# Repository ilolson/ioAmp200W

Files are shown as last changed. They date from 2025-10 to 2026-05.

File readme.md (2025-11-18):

# ioAmp200W

Small but powerful USB-C powered two channel speaker amplifier.

# Summary

Integrating the MA5332MS from infineon, a super efficient and compact 2 channel class D amplifier. With a TLV320AIC3254 mini DSP, a low power and compact DSP for consumer audio applications that will allow for tight integration. TPS26750 to control USB PD 3.1 EPR power supplies for up to 240W of DC power. An easy to use RP2350 microcontroller for high level control of the system, and hopefully digital audio in at 24bit/96khz.

The goal is to design a compact and efficient circuit board that can supply a wide range of power to the class D amplifier through USB-C Power Delivery. It will include line in and out for easy audio amplification. Including a quality and easy to use DSP such as the TLV320AIC3254 mini DSP should allow us to explore signal processing techniques to achieve optimal results at different power supply voltages, and different speaker setups. Digital audio in over USB-C should be possible in the future with the RP2350 and the DSP. For fun we can drive a HUB75 matrix panel in real time using existing optimized libraries with our signal.

# Power Supply

The USB PD 3.1 EPR can supply a maximum of 48V@5A for 240 watts DC. Even lower settings such as 20V/3A is a common laptop charging standard and many people already own USB-C bricks that can supply this which should be enough for some decent audio output, it also won't damage anything so it will be a safe default. The highest easily available is 28V@5A for 140W DC. 48V@5A is hard to find and expensive although I do plan on testing it on the first revision. 

# Major Circuits

-RP2350 microcontroller

-TI TPS26750 PD 3.1 EPR controller and power management system

-MA5332MS class D amplifier (up to 100W/Ch without heatsink)

-TLV3254AIC3254 low power consumer audio codec DSP, digital input from RP2350 and analog line in

# Highlights

-USB-C digital audio in (24 bit/96kHz)

-Program/Serial connectivity available while streaming audio over USB for easy real time DSP control

-Line In

-HUB75 interface (for driving LED matrix panels)

-High quality audio amplification at a manageable cost for DIY setups

-Wide range of easily available power supplies

# Status

-Initial schematic design

-Compilable firmware, serial and digital audio in working

-Auto install toolchain and compile scripts

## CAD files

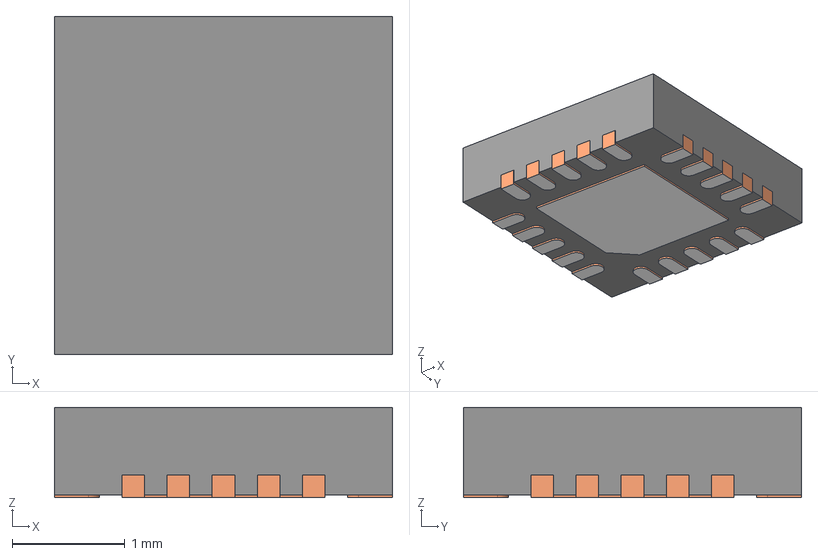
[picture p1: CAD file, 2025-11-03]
board/CustomLibs/TPD4S480RUKR/RUK0020B.stp
3.00 x 3.00 x 0.8 mm
BODY-QFN
FRAME-RUK0020B
PIN1-ID

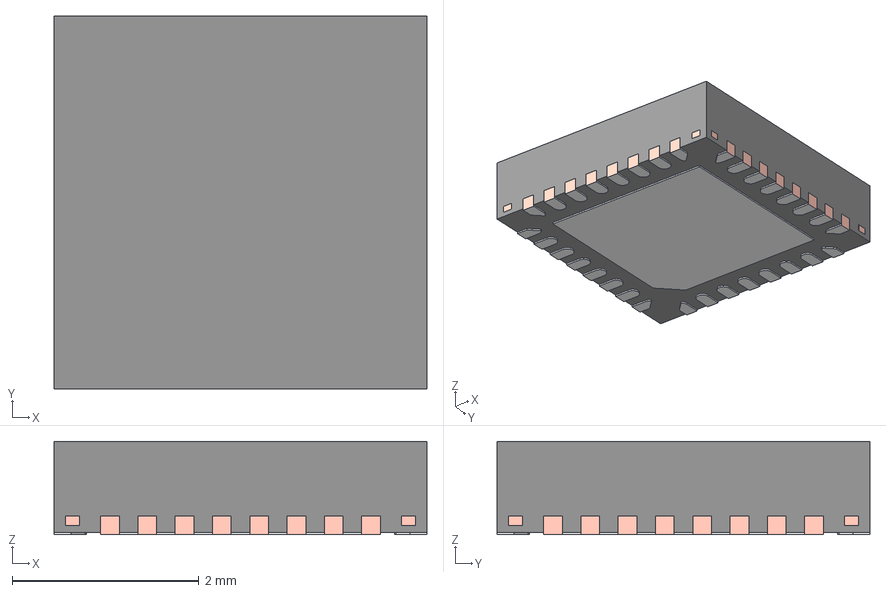
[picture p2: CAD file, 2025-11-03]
board/CustomLibs/TPS26750SRSMR/RSM0032B.stp
4.00 x 4.00 x 1.00 mm
BODY-QFN
FRAME-RSM0032B
PIN1-ID

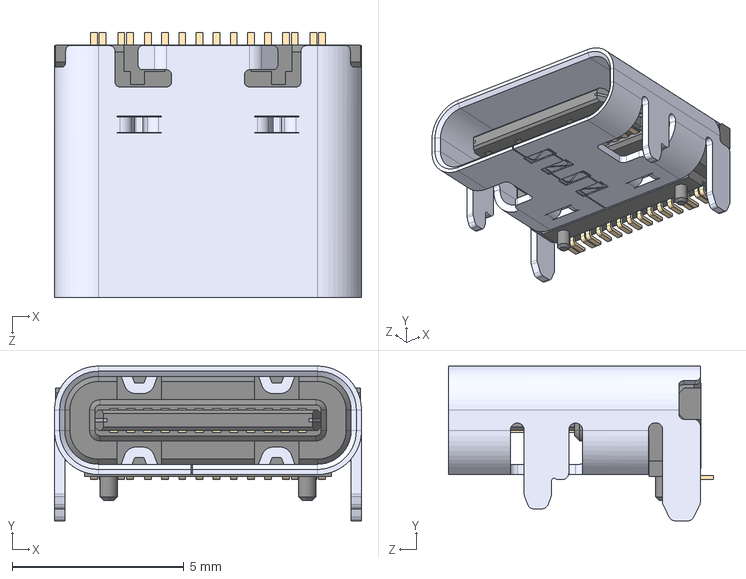
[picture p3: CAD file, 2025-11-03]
board/CustomLibs/USB4105_GF_A_120/USB4105-GF-A-120.step
8.94 x 4.51 x 7.71 mm

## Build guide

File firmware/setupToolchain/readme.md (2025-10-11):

# Toolchain Installation

Contains a script that installs the Raspberry Pi pico toolchain (and extras, for I2S) onto your machine and the additional dependancies required to build the application. *Run as sudo.*

Verified to work on macOS and Ubuntu 24.04 LTS (ARM and Windows through WSL2, recomended), this goes for the ```qbuild.sh``` script in the above directory.

```qbuild.sh``` skips dependancy and toolchain checks for fast build times.

Approx. 5.1 GB download size on WSL2

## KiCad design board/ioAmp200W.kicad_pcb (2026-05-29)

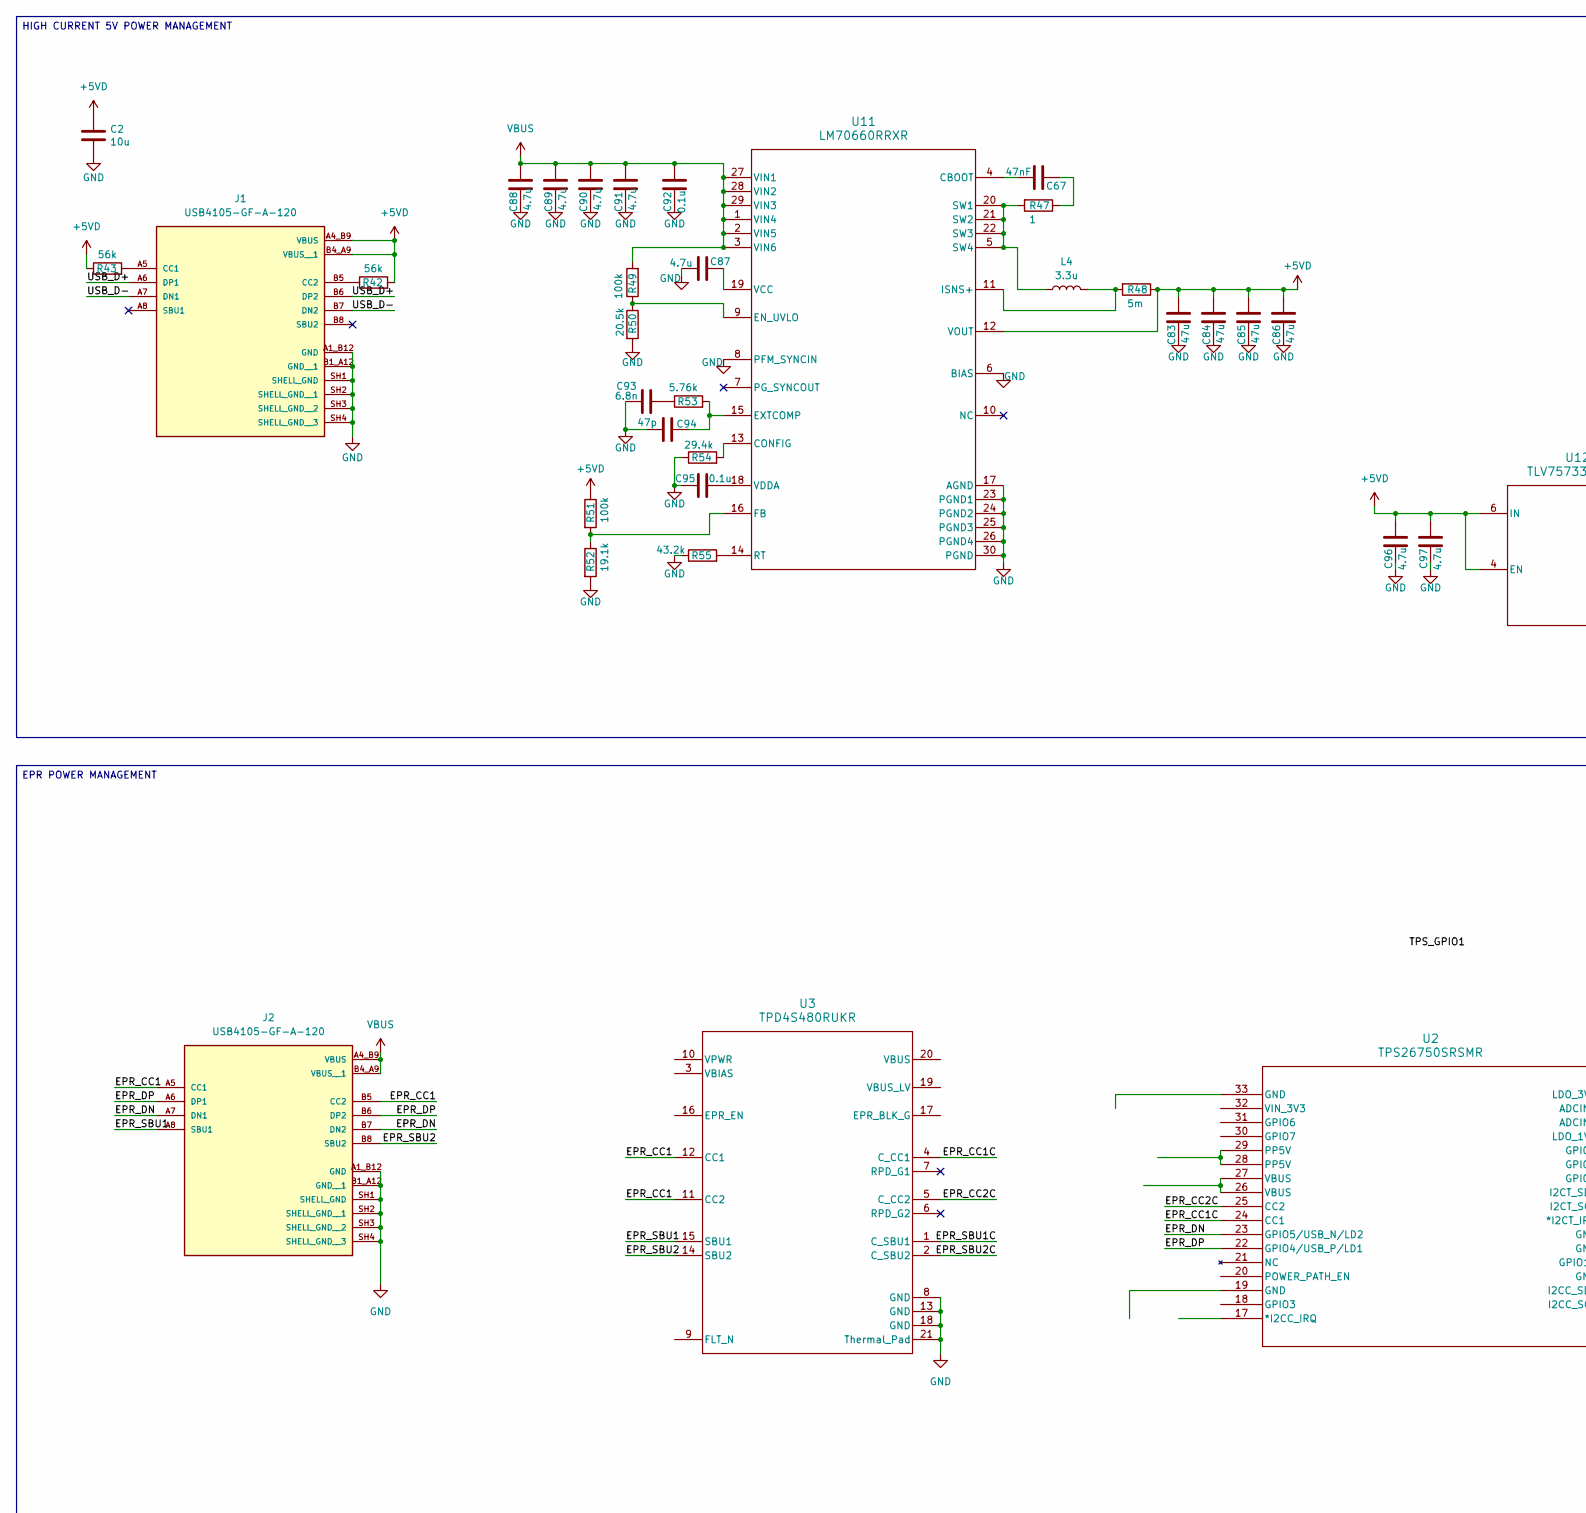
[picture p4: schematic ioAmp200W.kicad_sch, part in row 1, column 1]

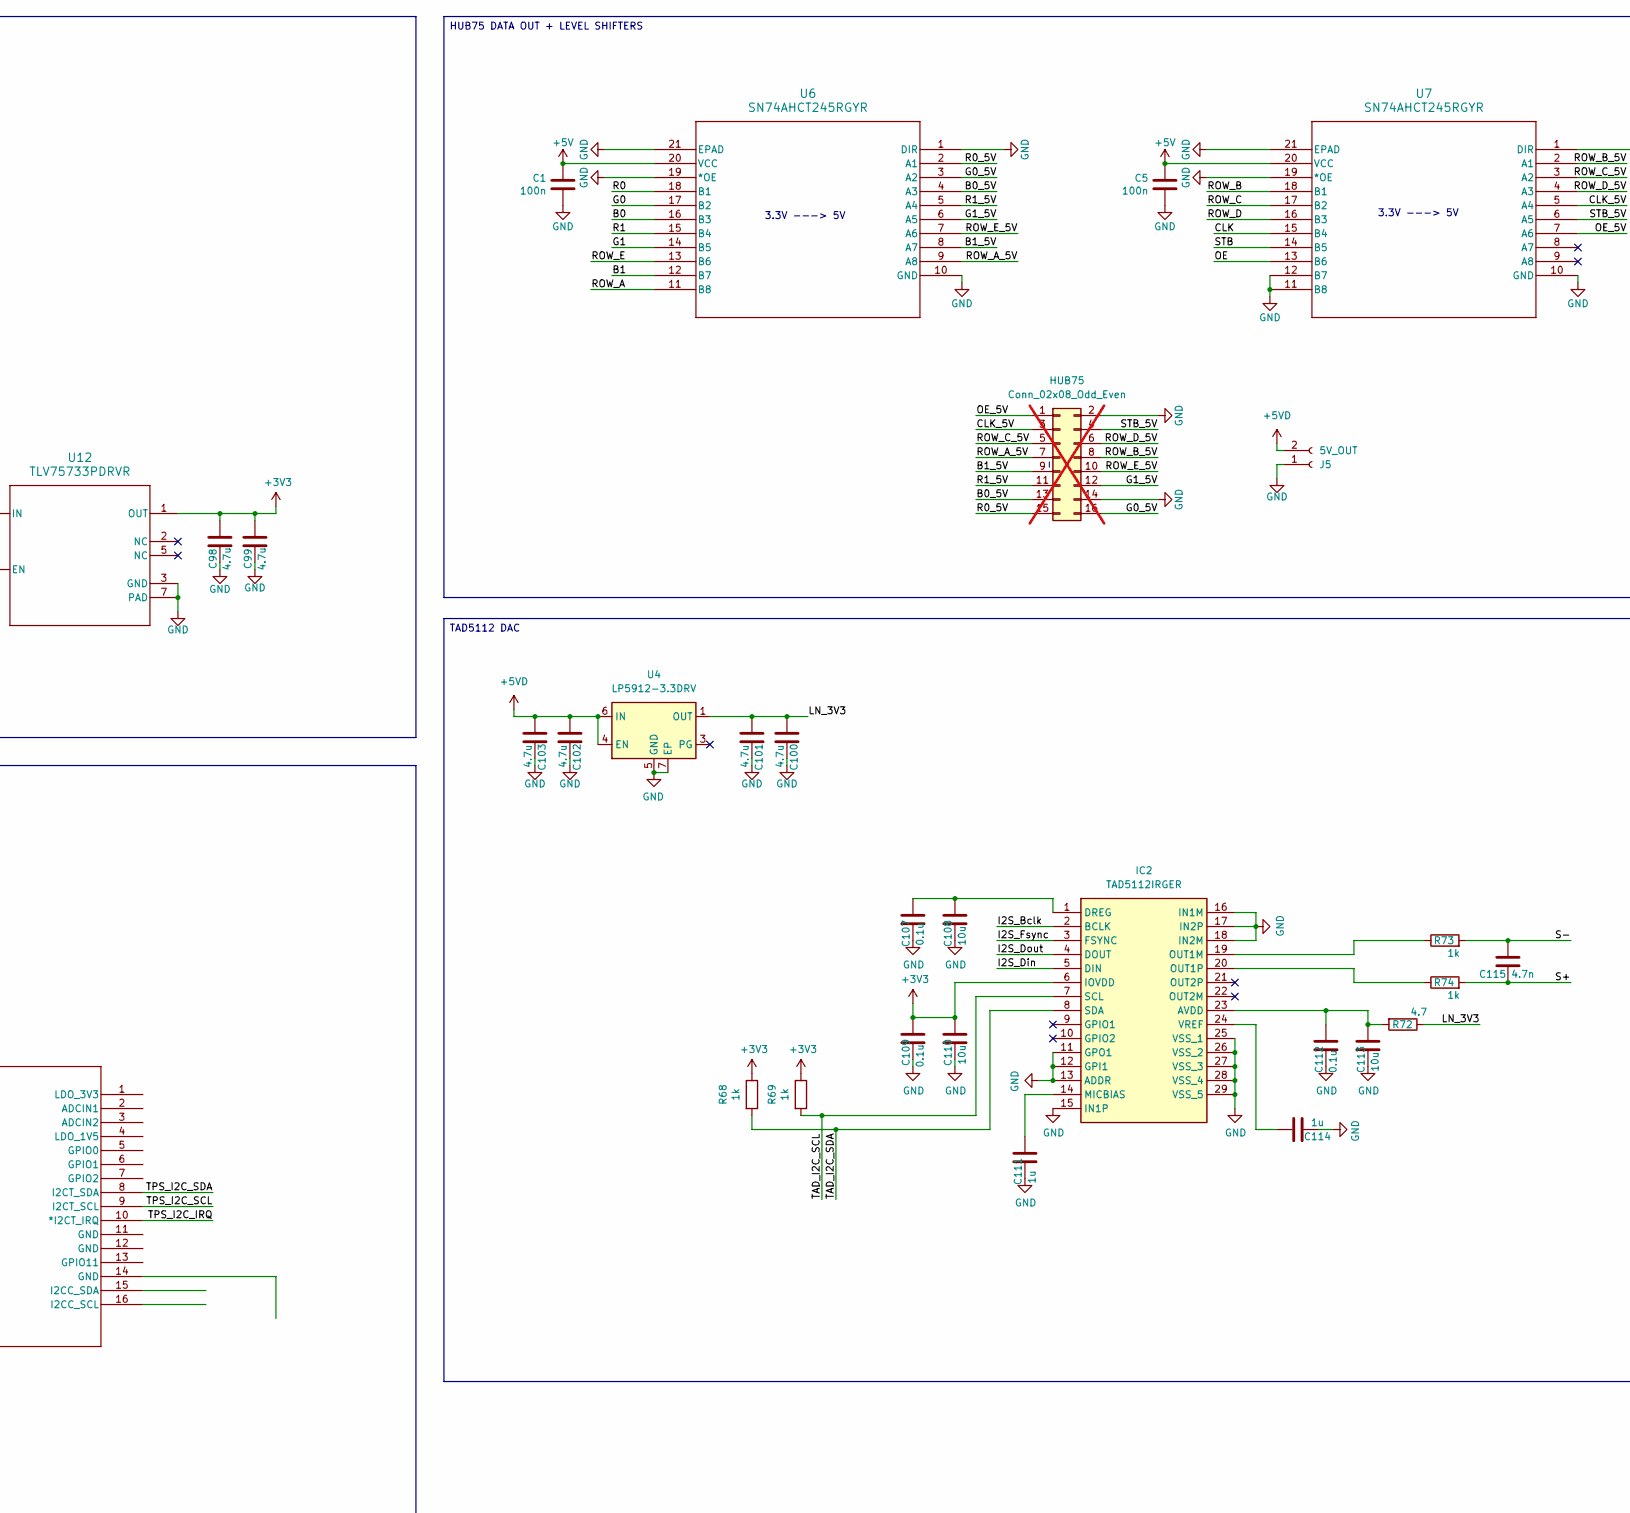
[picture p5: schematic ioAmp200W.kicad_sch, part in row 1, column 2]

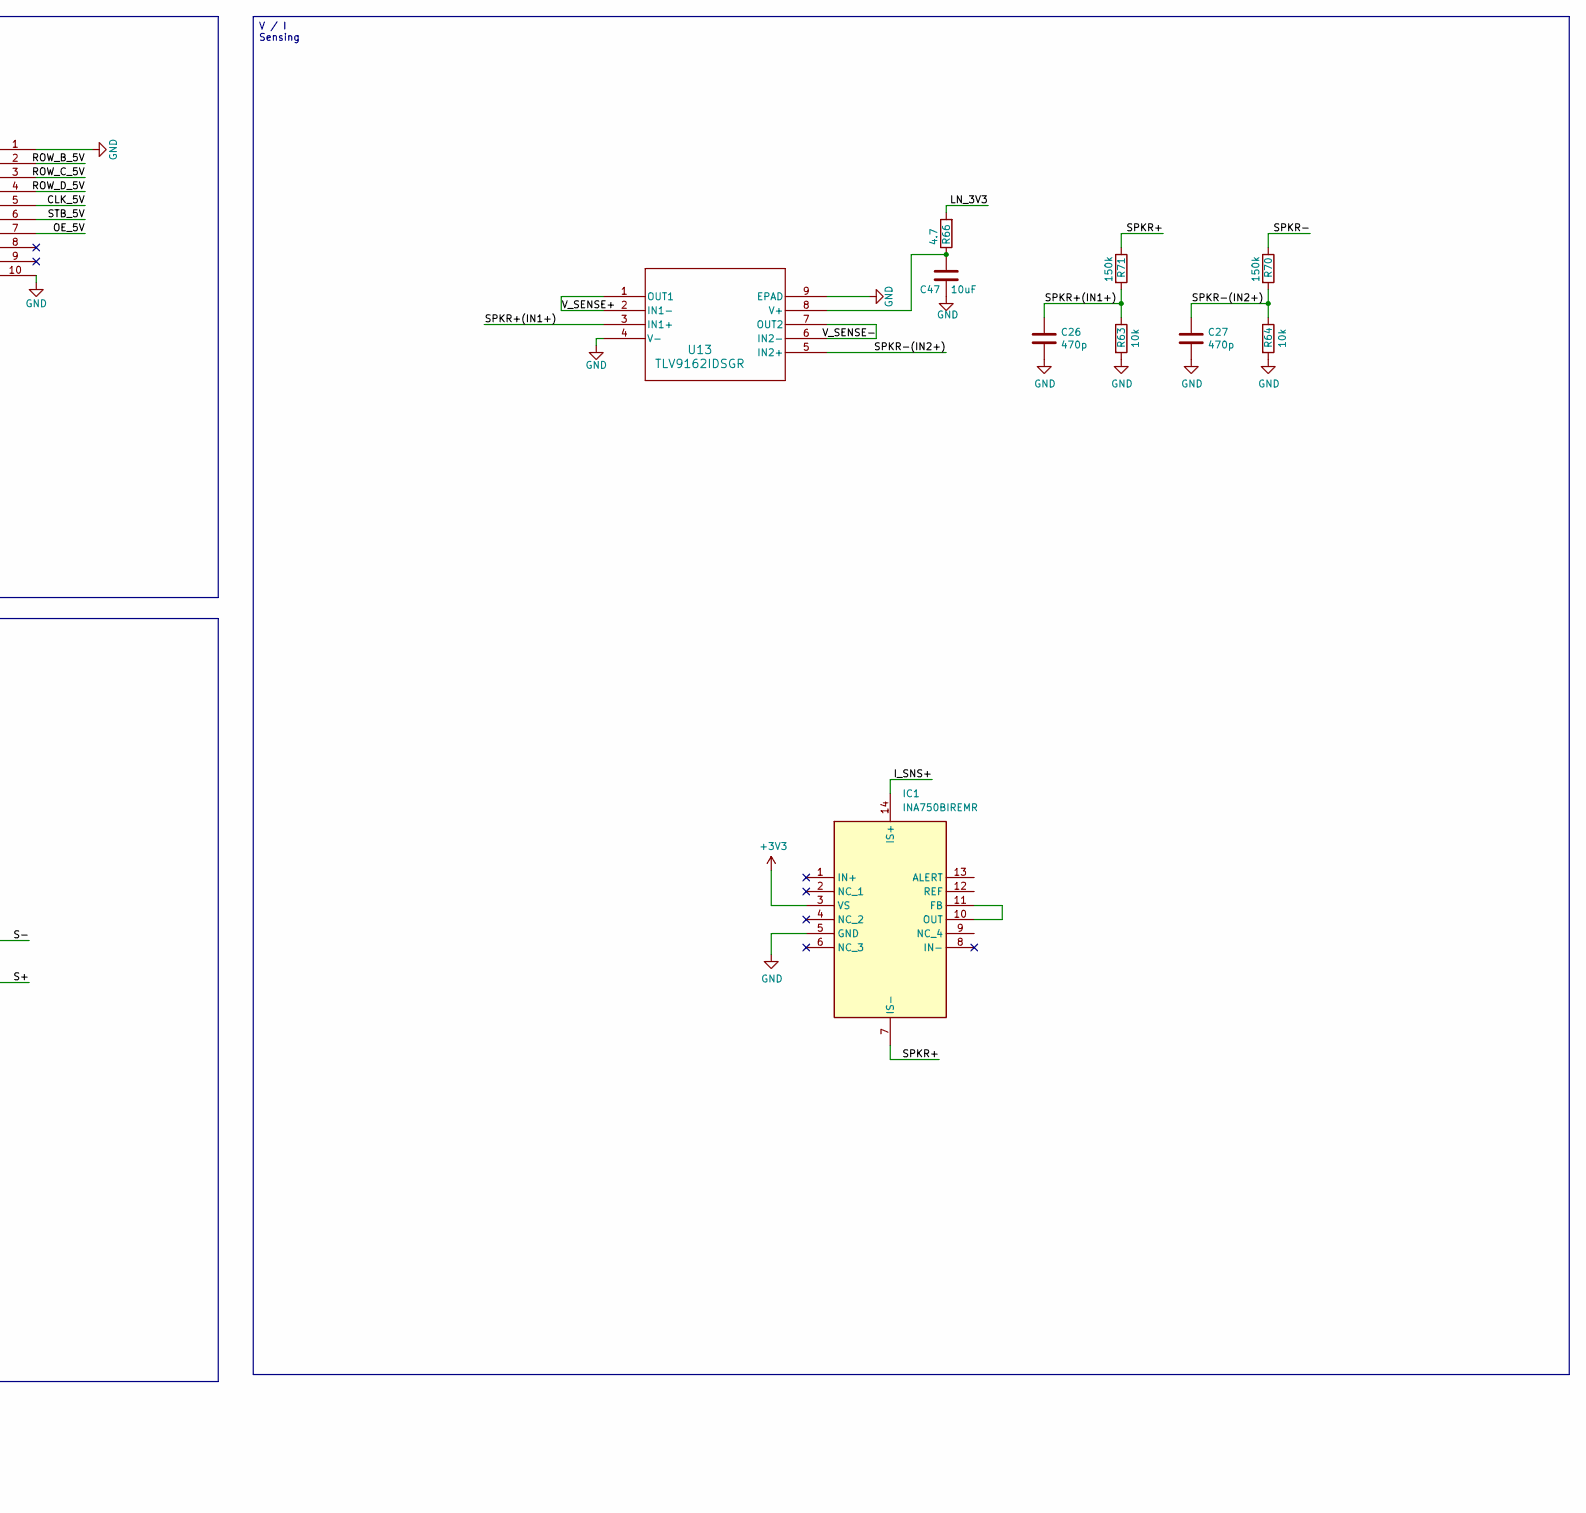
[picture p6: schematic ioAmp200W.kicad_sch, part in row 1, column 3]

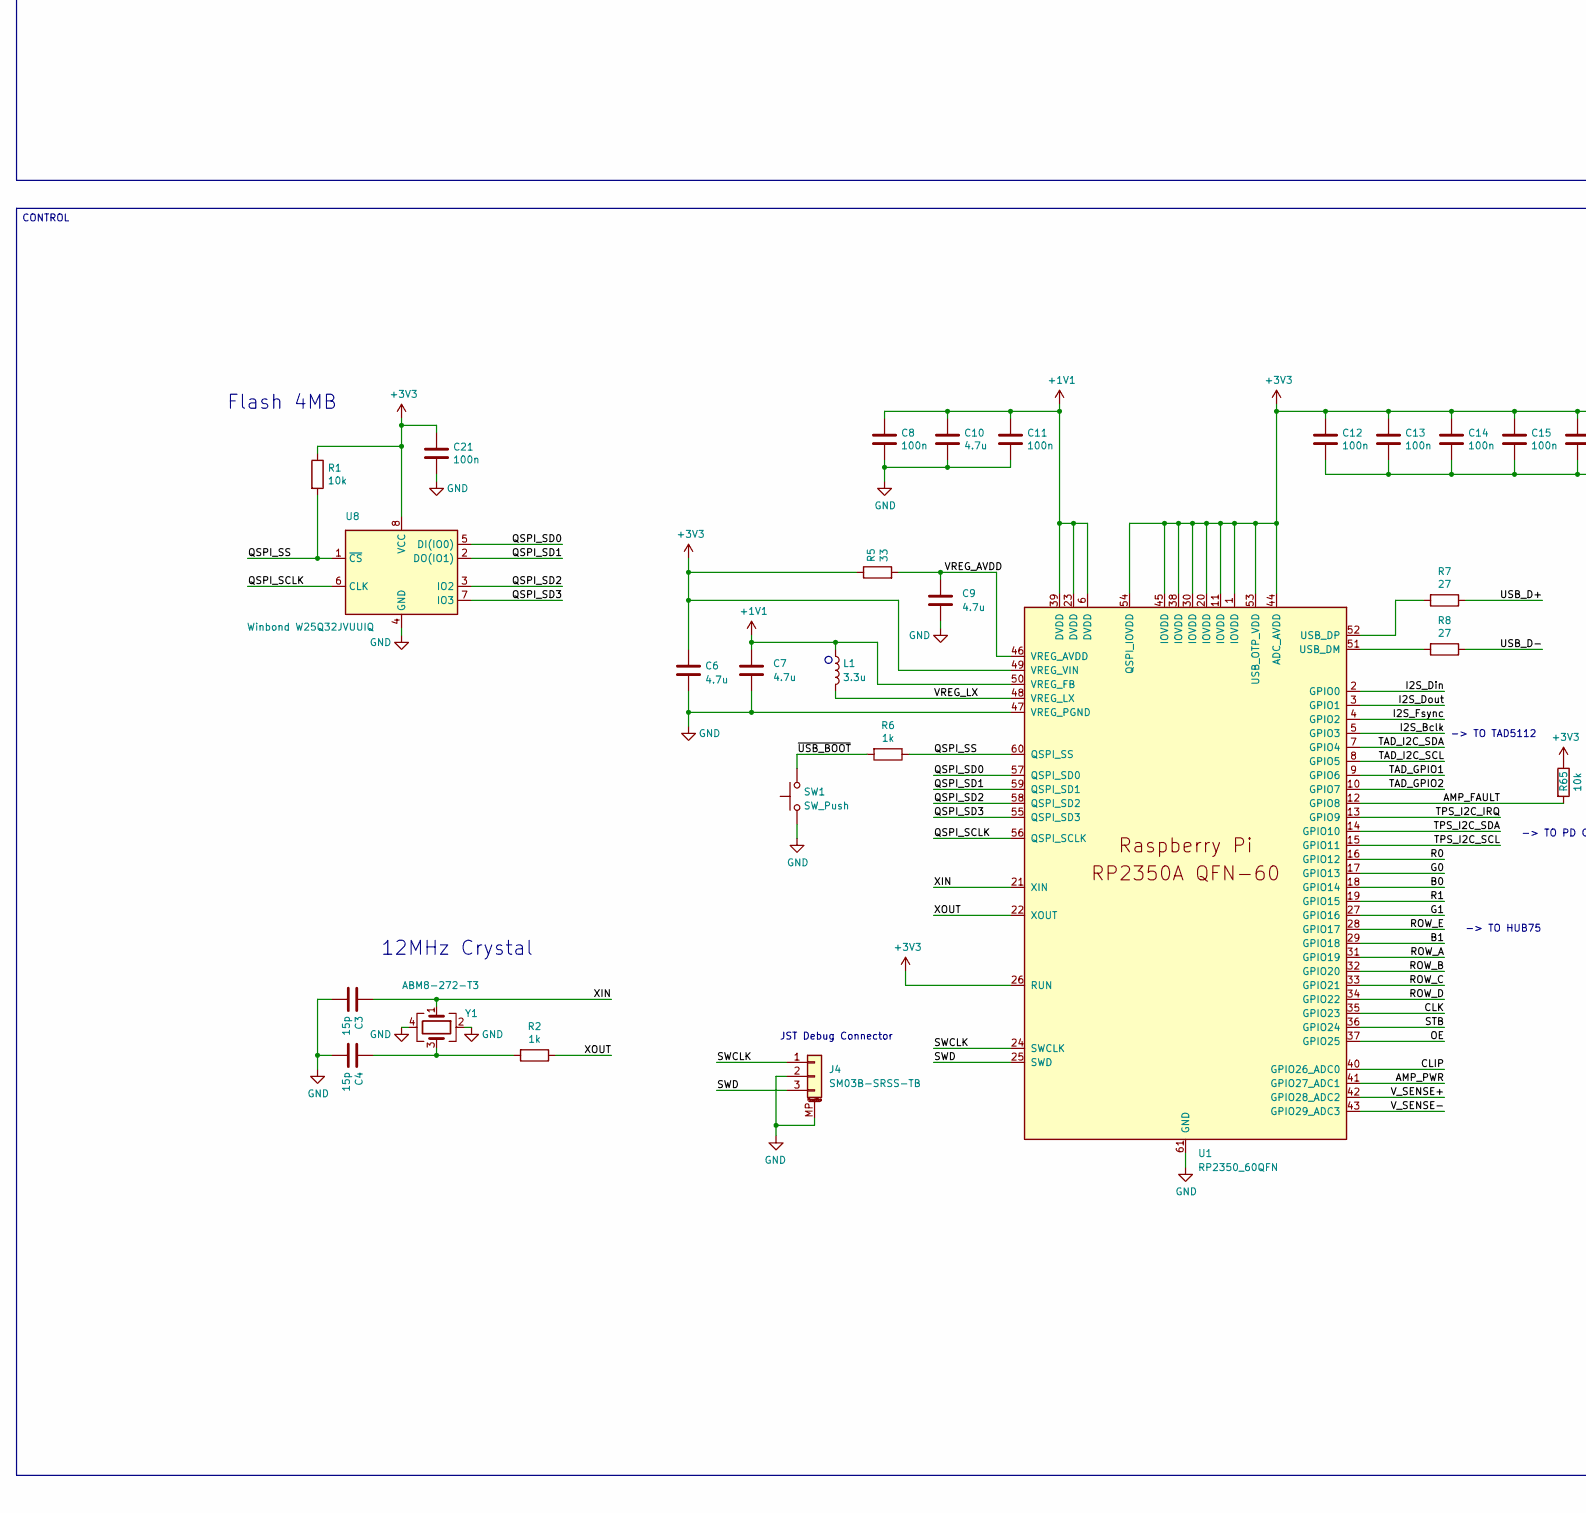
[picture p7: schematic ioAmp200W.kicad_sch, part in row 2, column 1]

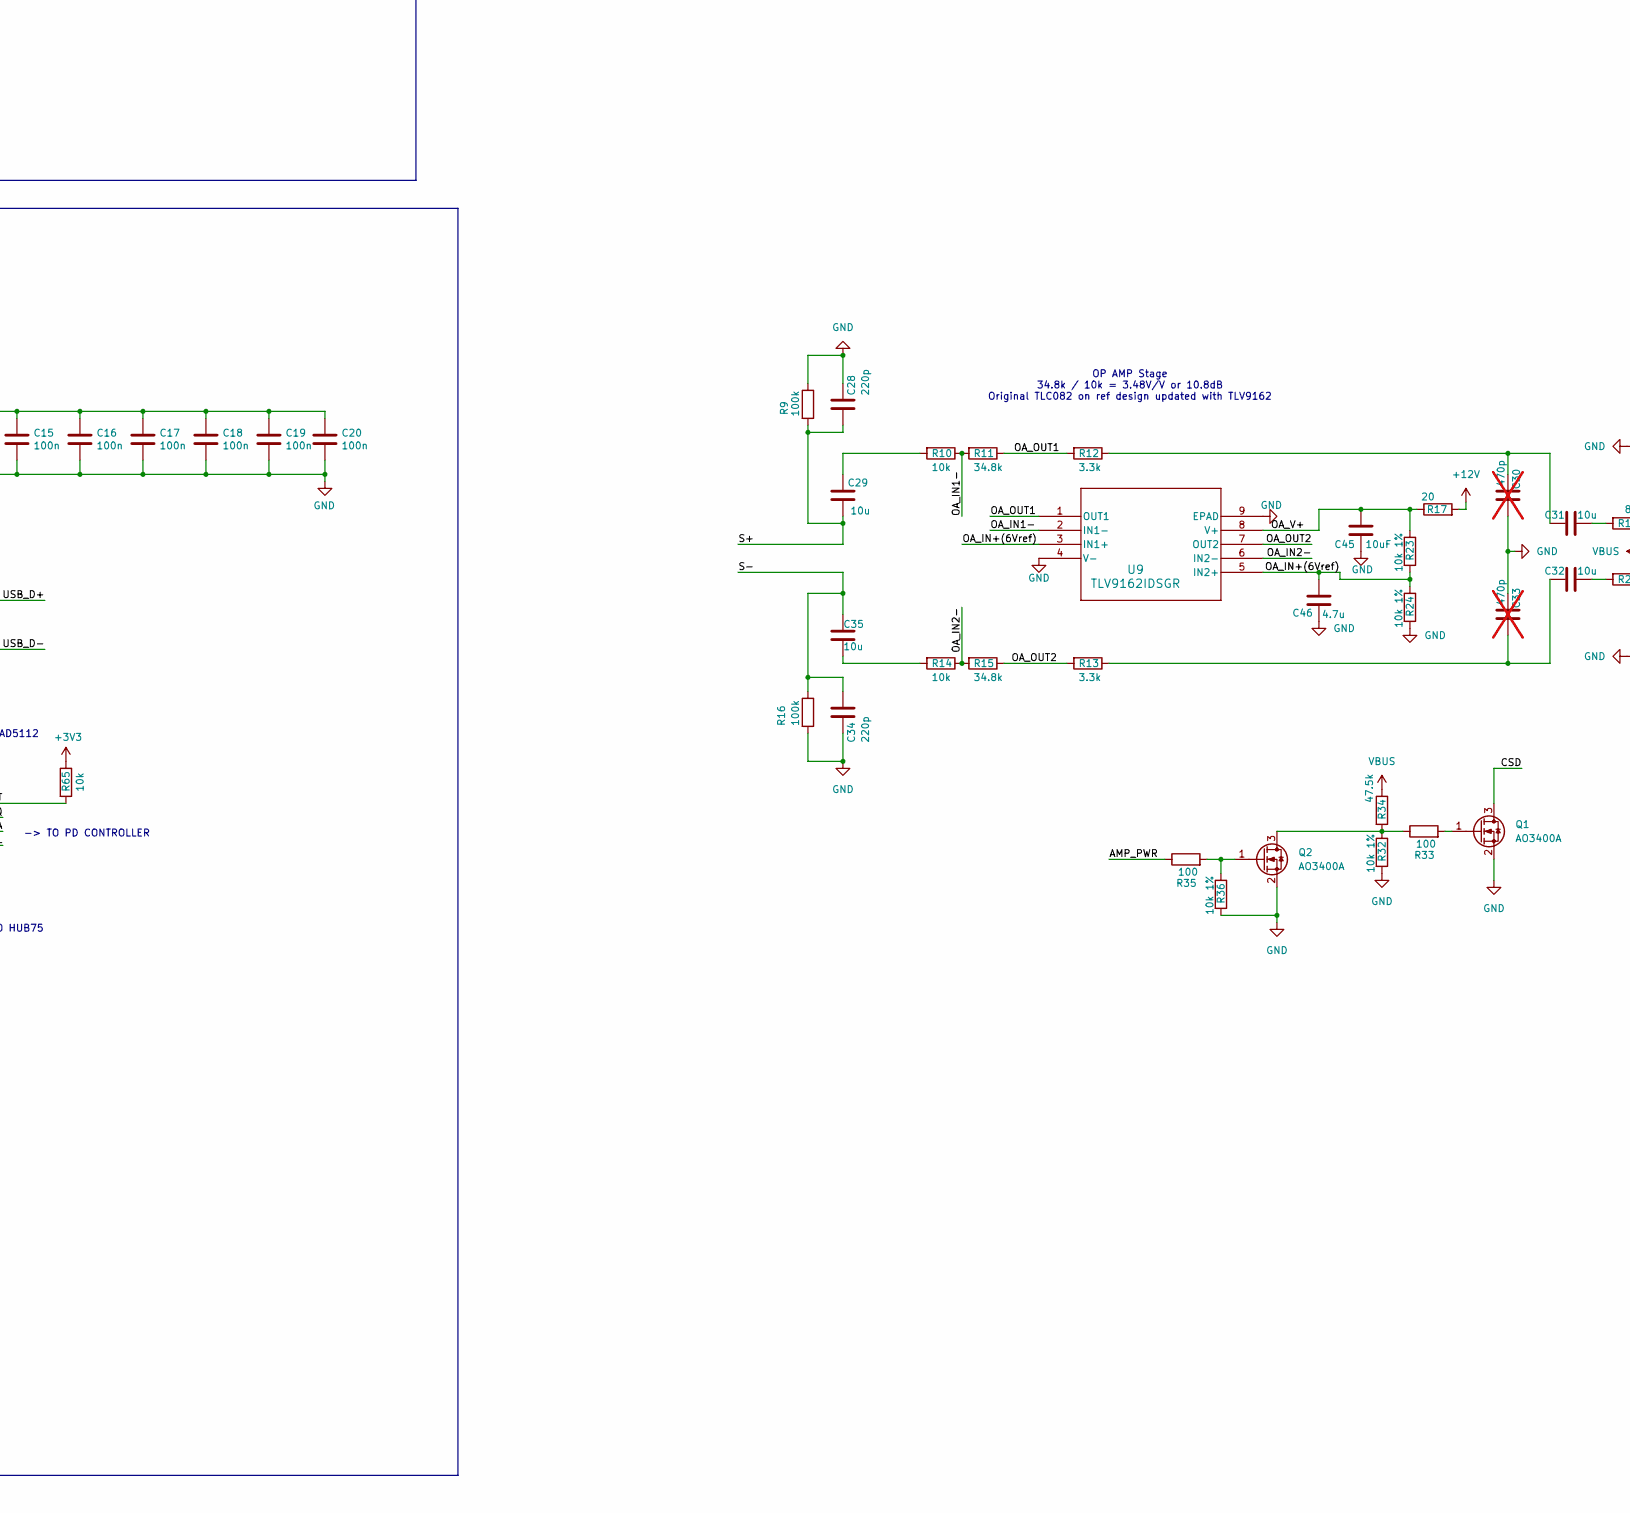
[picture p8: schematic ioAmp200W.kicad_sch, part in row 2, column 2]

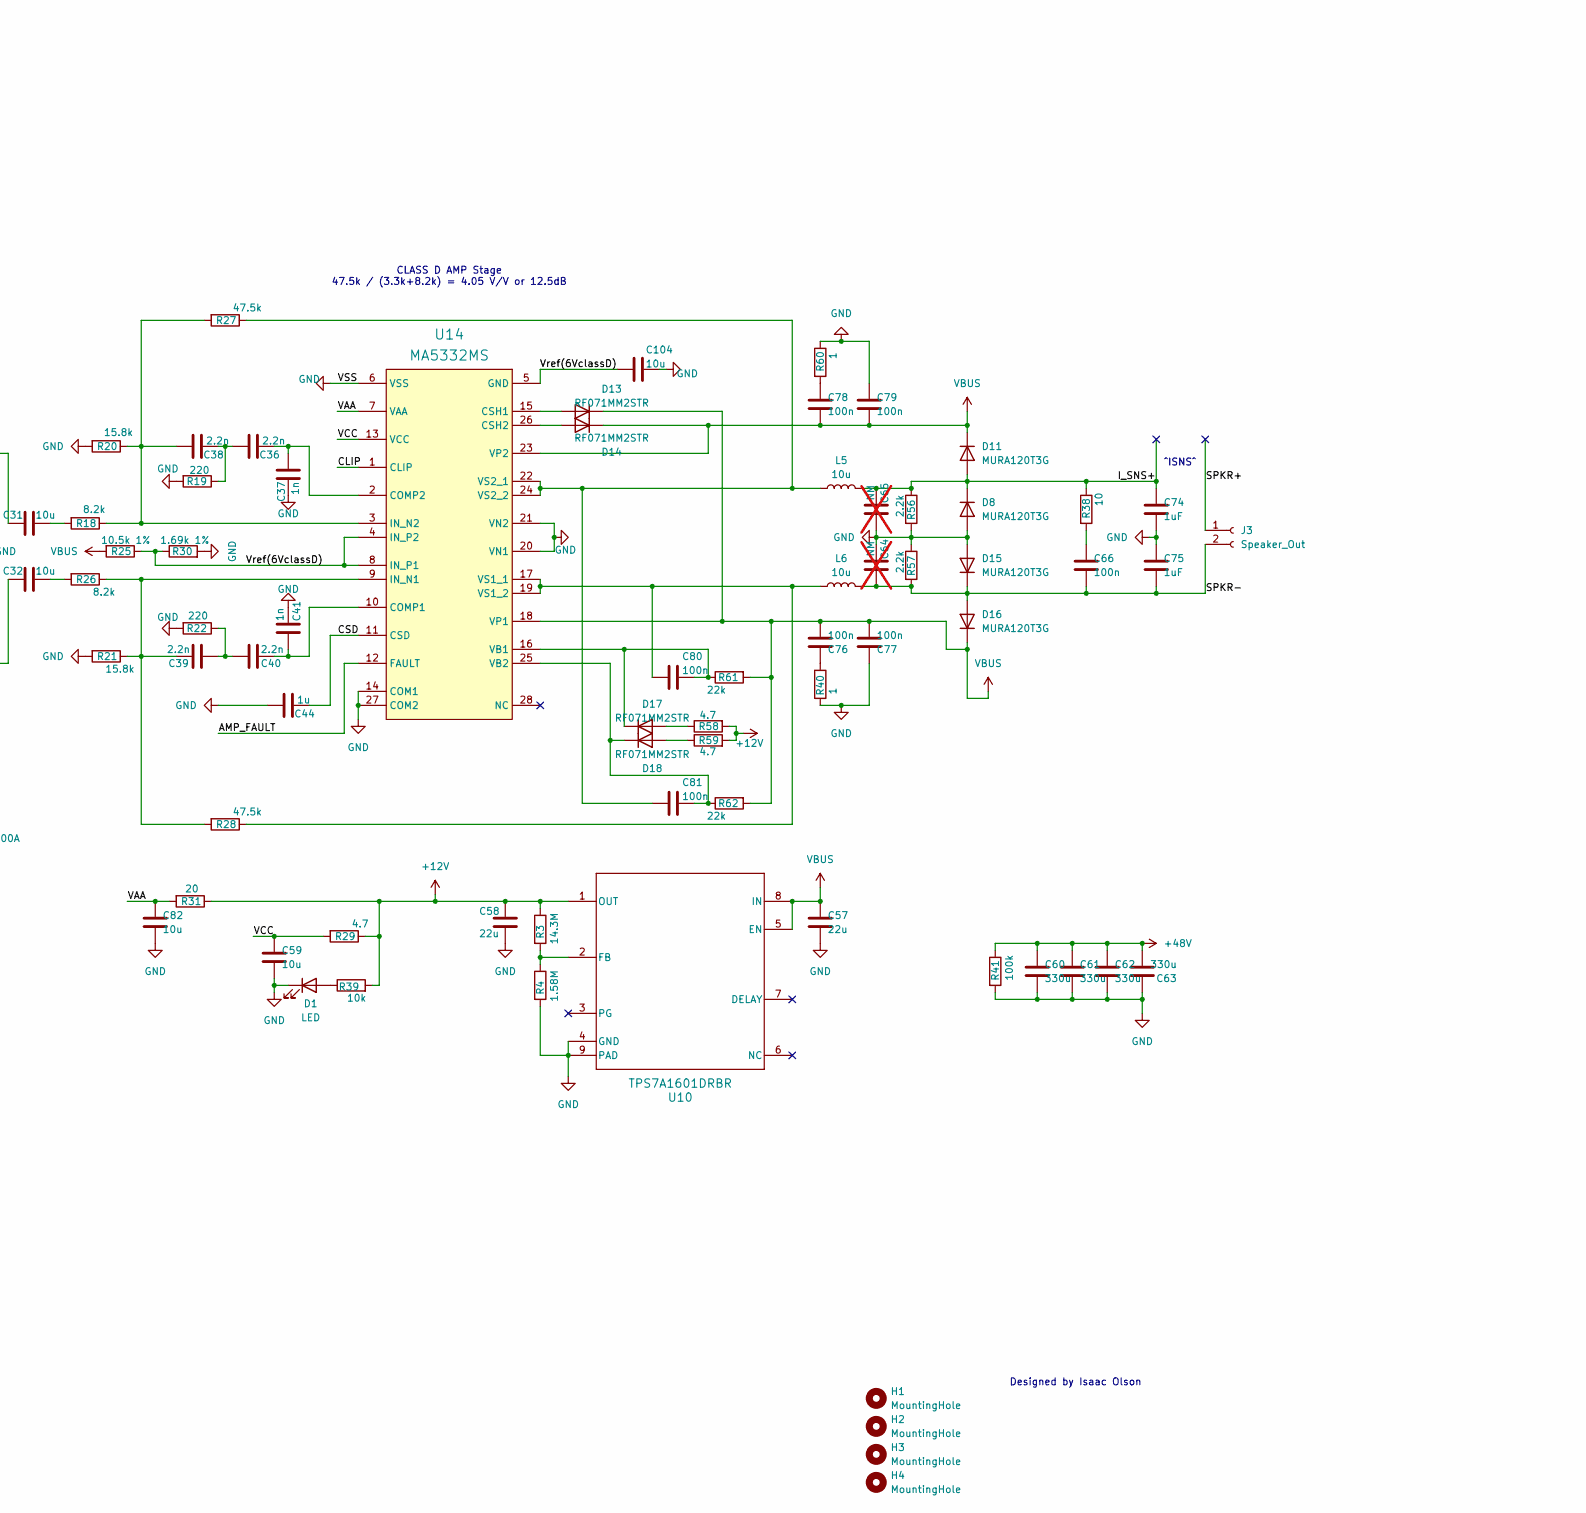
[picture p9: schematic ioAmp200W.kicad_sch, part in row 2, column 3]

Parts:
C1, C5, C8, C11, C12, C13, C14, C15, C16, C17, C18, C19, C20, C21, C66, C76, C77, C78, C79, C80, C81: 100n; C_0402_1005Metric
C2, C29, C31, C32, C35, C59, C82, C104, C108, C110, C113: 10u; C_0402_1005Metric
C3, C4: 15p; C_0402_1005Metric
C6, C7, C9, C10, C46: 4.7u; C_0402_1005Metric
C26, C27: 470p; C_0402_1005Metric
C28, C34: 220p; C_0402_1005Metric
C30, C33: 470p; C_0402_1005Metric; not fitted
C36, C38, C39, C40: 2.2n; C_0402_1005Metric
C37, C41: 1n; C_0402_1005Metric
C44, C111, C114: 1u; C_0402_1005Metric
C45, C47: 10uF; C_0402_1005Metric
C57, C58: 22u; C_0402_1005Metric
C60, C61, C62, C63: 330u; C_0402_1005Metric
C64, C65: NM; C_0402_1005Metric; not fitted
C67: 47nF; C_0402_1005Metric
C74, C75: 1uF
C83, C84, C85, C86: 47u; C_1210_3225Metric; LCSC C440151
C87, C88, C89, C90, C96, C98, C100, C102: 4.7u; C_1210_3225Metric; LCSC C913445
C91, C97, C99, C101, C103: 4.7u; C_1210_3225Metric
C92, C95, C107, C109, C112: 0.1u; C_0402_1005Metric
C93: 6.8n; C_0402_1005Metric
C94: 47p; C_0402_1005Metric
C115: 4.7n; C_0402_1005Metric
D1: LED; LED_0402_1005Metric
D8, D11, D15, D16: MURA120T3G; D_SMA; LCSC C111832
D13, D14, D17, D18: RF071MM2STR; D_SOD-123; LCSC C253520
H1, H2, H3, H4: MountingHole; MountingHole_2.1mm
HUB75: Conn_02x08_Odd_Even; IDC-Header_2x08_P2.54mm_Vertical_SMD; not fitted
IC1: INA750BIREMR; INA740BIREMR; Manufacturer_Part_Number INA750BIREMR
IC2: TAD5112IRGER; Manufacturer_Part_Number TAD5112IRGER
J1, J2: USB4105-GF-A-120; GCT_USB4105-GF-A-120; PARTREV B3
J3: Speaker_Out; AMASS_XT30U-F_1x02_P5.0mm_Vertical
J4: SM03B-SRSS-TB; JST_SH_SM03B-SRSS-TB_1x03-1MP_P1.00mm_Horizontal
J5: 5V_OUT; AMASS_XT30U-F_1x02_P5.0mm_Vertical
L1: 3.3u; L_pol_2016
L4: 3.3u; L_Bourns_SRP7028A_7.3x6.6mm; LCSC C3040366
L5, L6: 10u; C_0402_1005Metric
Q1, Q2: AO3400A; SOT-23; LCSC C347475
R1, R10, R14, R39, R63, R64, R65: 10k; R_0402_1005Metric
R2, R6, R68, R69, R73, R74: 1k; R_0402_1005Metric
R3: 14.3M; R_0402_1005Metric
R4: 1.58M; R_0402_1005Metric
R5: 33; R_0402_1005Metric
R7, R8: 27; R_0402_1005Metric
R9, R16, R41, R49, R51: 100k; R_0402_1005Metric
R11, R15: 34.8k; R_0402_1005Metric
R12, R13: 3.3k; R_0402_1005Metric
R17, R31: 20; R_0402_1005Metric
R18, R26: 8.2k; R_0402_1005Metric
R19, R22: 220; R_0402_1005Metric
R20, R21: 15.8k; R_0402_1005Metric
R23, R24, R32, R36: 10k 1%; R_0402_1005Metric
R25: 10.5k 1%; R_0402_1005Metric
R27, R28, R34: 47.5k; R_0402_1005Metric
R29, R58, R59, R66, R72: 4.7; R_0402_1005Metric
R30: 1.69k 1%; R_0402_1005Metric
R33, R35: 100; R_0402_1005Metric
R38: 10; R_0402_1005Metric
R40, R47, R60: 1; R_0402_1005Metric
R42, R43: 56k; R_0402_1005Metric
R48: 5m; R_1206_3216Metric; LCSC C6973817
R50: 20.5k; R_0402_1005Metric
R52: 19.1k; R_0402_1005Metric
R53: 5.76k; R_0402_1005Metric
R54: 29.4k; R_0402_1005Metric
R55: 43.2k; R_0402_1005Metric
R56, R57: 2.2k; R_0402_1005Metric
R61, R62: 22k; R_0402_1005Metric
R70, R71: 150k; R_0402_1005Metric
SW1: SW_Push; SW_SPST_TS-1088-xR020; LCSC C720477
U1: RP2350_60QFN; RP2350-QFN-60-1EP_7x7_P0.4mm_EP3.4x3.4mm_ThermalVias
U2: TPS26750SRSMR; VQFN32_RSM_TEX-L
U3: TPD4S480RUKR; RUK0020B-MFG
U4: LP5912-3.3DRV; WSON-6-1EP_2x2mm_P0.65mm_EP1x1.6mm
U6, U7: SN74AHCT245RGYR; DHVQFN-20-1EP_2.5x4.5mm_P0.5mm_EP1x3mm
U8: Winbond W25Q32JVUUIQ; Winbond_USON-8-2EP_3x4mm_P0.8mm_EP0.2x0.8mm; LCSC C2999380
U9, U13: TLV9162IDSGR; WSON8_DSG_TEX
U10: TPS7A1601DRBR; DRB0008B
U11: LM70660RRXR; RRX0029B-MFG
U12: TLV75733PDRVR; DRV0006A_NV
U14: MA5332MS; IFX-PG-IQFN-42-1-V
Y1: ABM8-272-T3; Crystal_SMD_3225-4Pin_3.2x2.5mm

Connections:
+1V1: C7.1, C8.1, C10.1, C11.1, L1.1, U1.6 (DVDD), U1.23 (DVDD), U1.39 (DVDD), U1.50 (VREG_FB)
+3V3: C6.1, C12.1, C13.1, C14.1, C15.1, C16.1, C17.1, C18.1, C19.1, C20.1, C21.1, C98.1, C99.1, C109.1, C110.1, IC1.3 (VS), IC2.6 (IOVDD), R1.1, R5.1, R65.1, R68.1, R69.1, U1.1 (IOVDD), U1.11 (IOVDD), U1.20 (IOVDD), U1.26 (RUN), U1.30 (IOVDD), U1.38 (IOVDD), U1.44 (ADC_AVDD), U1.45 (IOVDD), U1.49 (VREG_VIN), U1.53 (USB_OTP_VDD), U1.54 (QSPI_IOVDD), U8.8 (VCC), U12.1 (OUT)
+5V: C1.1, C5.1, U6.20 (VCC), U7.20 (VCC)
+5VD: C2.1, C83.1, C84.1, C85.1, C86.1, C96.1, C97.1, C102.1, C103.1, J1.A4_B9 (VBUS), J1.B4_A9 (VBUS__1), J5.2, R42.2, R43.1, R48.1, R51.1, U4.4 (EN), U4.6 (IN), U11.12 (VOUT), U12.4 (EN), U12.6 (IN)
+12V: C58.2, R3.1, R17.2, R29.1, R31.1, R39.2, R58.2, R59.2, U10.1 (OUT)
+48V: C60.2, C61.2, C62.2, C63.2, R41.1
/AMP_FAULT: R65.2, U1.12 (GPIO8), U14.12 (FAULT)
/AMP_PWR: R35.1, U1.41 (GPIO27_ADC1)
/B0: U1.18 (GPIO14), U6.16 (B3)
/B0_5V: HUB75.13, U6.4 (A3)
/B1: U1.29 (GPIO18), U6.12 (B7)
/B1_5V: HUB75.9, U6.8 (A7)
/CLIP: U1.40 (GPIO26_ADC0), U14.1 (CLIP)
/CLK: U1.35 (GPIO23), U7.15 (B4)
/CLK_5V: HUB75.3, U7.5 (A4)
/CSD: C44.1, Q1.3 (D), U14.11 (CSD)
/EPR_CC1: J2.A5 (CC1), J2.B5 (CC2), U3.11 (CC2), U3.12 (CC1)
/EPR_CC1C: U2.24 (CC1), U3.4 (C_CC1)
/EPR_CC2C: U2.25 (CC2), U3.5 (C_CC2)
/EPR_DN: J2.A7 (DN1), J2.B7 (DN2), U2.23 (GPIO5/USB_N/LD2)
/EPR_DP: J2.A6 (DP1), J2.B6 (DP2), U2.22 (GPIO4/USB_P/LD1)
/EPR_SBU1: J2.A8 (SBU1), U3.15 (SBU1)
/EPR_SBU1C: U3.1 (C_SBU1)
/EPR_SBU2: J2.B8 (SBU2), U3.14 (SBU2)
/EPR_SBU2C: U3.2 (C_SBU2)
/G0: U1.17 (GPIO13), U6.17 (B2)
/G0_5V: HUB75.16, U6.3 (A2)
/G1: U1.27 (GPIO16), U6.14 (B5)
/G1_5V: HUB75.12, U6.6 (A5)
/I2S_Bclk: IC2.2 (BCLK), U1.5 (GPIO3)
/I2S_Din: IC2.5 (DIN), U1.2 (GPIO0)
/I2S_Dout: IC2.4 (DOUT), U1.3 (GPIO1)
/I2S_Fsync: IC2.3 (FSYNC), U1.4 (GPIO2)
/LN_3V3: C100.1, C101.1, R66.2, R72.1, U4.1 (OUT)
/OA_IN1-: R10.1, R11.2, U9.2 (IN1-)
/OA_IN2-: R14.1, R15.2, U9.6 (IN2-)
/OA_IN+(6Vref): C46.2, R23.2, R24.1, U9.3 (IN1+), U9.5 (IN2+)
/OA_OUT1: R11.1, R12.2, U9.1 (OUT1)
/OA_OUT2: R13.2, R15.1, U9.7 (OUT2)
/OA_V+: C45.2, R17.1, R23.1, U9.8 (V+)
/OE: U1.37 (GPIO25), U7.13 (B6)
/OE_5V: HUB75.1, U7.7 (A6)
/QSPI_SCLK: U1.56 (QSPI_SCLK), U8.6 (CLK)
/QSPI_SD0: U1.57 (QSPI_SD0), U8.5 (DI(IO0))
/QSPI_SD1: U1.59 (QSPI_SD1), U8.2 (DO(IO1))
/QSPI_SD2: U1.58 (QSPI_SD2), U8.3 (IO2)
/QSPI_SD3: U1.55 (QSPI_SD3), U8.7 (IO3)
/QSPI_SS: R1.2, R6.1, U1.60 (QSPI_SS), U8.1 (~CS)
/R0: U1.16 (GPIO12), U6.18 (B1)
/R0_5V: HUB75.15, U6.2 (A1)
/R1: U1.19 (GPIO15), U6.15 (B4)
/R1_5V: HUB75.11, U6.5 (A4)
/ROW_A: U1.31 (GPIO19), U6.11 (B8)
/ROW_A_5V: HUB75.7, U6.9 (A8)
/ROW_B: U1.32 (GPIO20), U7.18 (B1)
/ROW_B_5V: HUB75.8, U7.2 (A1)
/ROW_C: U1.33 (GPIO21), U7.17 (B2)
/ROW_C_5V: HUB75.5, U7.3 (A2)
/ROW_D: U1.34 (GPIO22), U7.16 (B3)
/ROW_D_5V: HUB75.6, U7.4 (A3)
/ROW_E: U1.28 (GPIO17), U6.13 (B6)
/ROW_E_5V: HUB75.10, U6.7 (A6)
/S+: C28.2, C29.2, C115.2, R9.2, R74.2
/S-: C34.1, C35.1, C115.1, R16.1, R73.2
/SENSE+: U1.42 (GPIO28_ADC2), U13.1 (OUT1), U13.2 (IN1-)
/SENSE-: U1.43 (GPIO29_ADC3), U13.6 (IN2-), U13.7 (OUT2)
/SPKR+(IN1+): C26.1, R63.1, R71.2, U13.3 (IN1+)
/SPKR-: C64.2, C66.1, C75.1, D15.1 (K), D16.2 (A), J3.2, L6.2, R57.2, R70.1
/SPKR-(IN2+): C27.1, R64.1, R70.2, U13.5 (IN2+)
/STB: U1.36 (GPIO24), U7.14 (B5)
/STB_5V: HUB75.4, U7.6 (A5)
/SWCLK: J4.1, U1.24 (SWCLK)
/SWD: J4.3, U1.25 (SWD)
/TAD_GPIO1: U1.9 (GPIO6)
/TAD_GPIO2: U1.10 (GPIO7)
/TAD_I2C_SCL: IC2.7 (SCL), R69.2, U1.8 (GPIO5)
/TAD_I2C_SDA: IC2.8 (SDA), R68.2, U1.7 (GPIO4)
/TPS_I2C_IRQ: U1.13 (GPIO9), U2.10 (*I2CT_IRQ)
/TPS_I2C_SCL: U1.15 (GPIO11), U2.9 (I2CT_SCL)
/TPS_I2C_SDA: U1.14 (GPIO10), U2.8 (I2CT_SDA)
/USB_D+: J1.A6 (DP1), J1.B6 (DP2), R7.1
/USB_D-: J1.A7 (DN1), J1.B7 (DN2), R8.1
/VAA: C82.2, R31.2, U14.7 (VAA)
/VCC: C59.2, R29.2, U14.13 (VCC)
/VREG_AVDD: C9.1, R5.2, U1.46 (VREG_AVDD)
/VREG_LX: L1.2, U1.48 (VREG_LX)
/Vref(6VclassD): C104.1, R25.1, R30.1, U14.4 (IN_P2), U14.5 (GND), U14.8 (IN_P1)
/XIN: C3.1, U1.21 (XIN), Y1.1
/XOUT: R2.1, U1.22 (XOUT)
/~USB_BOOT: R6.2, SW1.2
GND: C1.2, C2.2, C3.2, C4.2, C5.2, C6.2, C7.2, C8.2, C9.2, C10.2, C11.2, C12.2, C13.2, C14.2, C15.2, C16.2, C17.2, C18.2, C19.2, C20.2, C21.2, C26.2, C27.2, C28.1, C30.2, C33.1, C34.2, C37.2, C41.1, C44.2, C45.1, C46.1, C47.1, C57.1, C58.1, C59.1, C60.1, C61.1, C62.1, C63.1, C64.1, C65.2, C74.1, C75.2, C77.2, C79.2, C82.1, C83.2, C84.2, C85.2, C86.2, C87.2, C88.2, C89.2, C90.2, C91.2, C92.2, C93.2, C94.2, C95.2, C96.2, C97.2, C98.2, C99.2, C100.2, C101.2, C102.2, C103.2, C104.2, C107.2, C108.2, C109.2, C110.2, C111.2, C112.2, C113.2, C114.2, D1.1 (K), D8.2 (A), D15.2 (A), HUB75.2, HUB75.14, IC1.5 (GND), IC2.11 (GPO1), IC2.12 (GPI1), IC2.13 (ADDR), IC2.15 (IN1P), IC2.16 (IN1M), IC2.17 (IN2P), IC2.18 (IN2M), IC2.25 (VSS_1), IC2.26 (VSS_2), IC2.27 (VSS_3), IC2.28 (VSS_4), IC2.29 (VSS_5), J1.A1_B12 (GND), J1.B1_A12 (GND__1), J1.SH1 (SHELL_GND), J1.SH2 (SHELL_GND__1), J1.SH3 (SHELL_GND__2), J1.SH4 (SHELL_GND__3), J2.A1_B12 (GND), J2.B1_A12 (GND__1), J2.SH1 (SHELL_GND), J2.SH2 (SHELL_GND__1), J2.SH3 (SHELL_GND__2), J2.SH4 (SHELL_GND__3), J4.2, J4.MP (MountPin), J5.1, Q1.2 (S), Q2.2 (S), R4.2, R9.1, R16.2, R19.2, R20.2, R21.2, R22.2, R24.2, R30.2, R32.2, R36.2, R40.1, R41.2, R50.2, R52.2, R54.1, R55.1, R56.2, R57.1, R60.1, R63.2, R64.2, SW1.1, U1.47 (VREG_PGND), U1.61 (GND), U3.8 (GND), U3.13 (GND), U3.18 (GND), U3.21 (Thermal_Pad), U4.5 (GND), U4.7 (EP), U6.1 (DIR), U6.10 (GND), U6.19 (*OE), U6.21 (EPAD), U7.1 (DIR), U7.10 (GND), U7.11 (B8), U7.12 (B7), U7.19 (*OE), U7.21 (EPAD), U8.4 (GND), U9.4 (V-), U9.9 (EPAD), U10.4 (GND), U10.9 (PAD), U11.6 (BIAS), U11.8 (PFM_SYNCIN), U11.17 (AGND), U11.23 (PGND1), U11.24 (PGND2), U11.25 (PGND3), U11.26 (PGND4), U11.30 (PGND), U12.3 (GND), U12.7 (PAD), U13.4 (V-), U13.9 (EPAD), U14.6 (VSS), U14.14 (COM1), U14.20 (VN1), U14.21 (VN2), U14.27 (COM2), Y1.2, Y1.4; also elsewhere on the board
unnamed: C4.1, R2.2, Y1.3
unnamed: C29.1, R10.2
unnamed: C30.1, C31.1, R12.1
unnamed: C31.2, R18.2
unnamed: C32.1, C33.2, R13.1
unnamed: C32.2, R26.2
unnamed: C35.2, R14.2
unnamed: C36.2, C38.1, R19.1
unnamed: C39.1, C40.2, R22.1
unnamed: C66.2, R38.2
unnamed: C67.1, R47.1
unnamed: C76.2, R40.2
unnamed: C78.2, R60.2
unnamed: C93.1, R53.1
unnamed: D1.2 (A), R39.1
unnamed: D13.2 (A), U14.15 (CSH1)
unnamed: D14.2 (A), U14.26 (CSH2)
unnamed: D17.2 (A), R58.1
unnamed: C80.2, D17.1 (K), R61.1, U14.16 (VB1)
unnamed: D18.2 (A), R59.1
unnamed: C81.2, D18.1 (K), R62.1, U14.25 (VB2)
unnamed: C112.1, C113.1, IC2.23 (AVDD), R72.2
unnamed: C107.1, C108.1, IC2.1 (DREG)
unnamed: C111.1, IC2.14 (MICBIAS)
unnamed: IC2.19 (OUT1M), R73.1
unnamed: IC2.20 (OUT1P), R74.1
unnamed: C114.1, IC2.24 (VREF)
unnamed 118: J1.A5 (CC1), R43.2; also elsewhere on the board
unnamed 119: J1.B5 (CC2), R42.1; also elsewhere on the board
unnamed: Q1.1 (G), R33.2
unnamed: Q2.3 (D), R32.1, R33.1, R34.2
unnamed: Q2.1 (G), R35.2, R36.1
unnamed: R8.2, U1.51 (USB_DM)
unnamed: R7.2, U1.52 (USB_DP)
unnamed: U2.28 (PP5V), U2.29 (PP5V)
unnamed: U2.26 (VBUS), U2.27 (VBUS)
unnamed: R3.2, R4.1, U10.2 (FB)
unnamed: C67.2, U11.4 (CBOOT)
unnamed: R54.2, U11.13 (CONFIG)
unnamed: R49.1, R50.1, U11.9 (EN_UVLO)
unnamed: C94.1, R53.2, U11.15 (EXTCOMP)
unnamed: R51.2, R52.1, U11.16 (FB)
unnamed: L4.2, R48.2, U11.11 (ISNS+)
unnamed: R55.2, U11.14 (RT)
unnamed: L4.1, R47.2, U11.5 (SW4), U11.20 (SW1), U11.21 (SW2), U11.22 (SW3)
unnamed: C87.1, U11.19 (VCC)
unnamed: C95.1, U11.18 (VDDA)
unnamed: C47.2, R66.1, U13.8 (V+)
unnamed: C40.1, C41.2, U14.10 (COMP1)
unnamed: C36.1, C37.1, U14.2 (COMP2)
unnamed: C39.2, R21.1, R26.1, R28.2, U14.9 (IN_N1)
unnamed: C38.2, R18.1, R20.1, R27.2, U14.3 (IN_N2)
unnamed: C80.1, L6.1, R28.1, U14.17 (VS1_1), U14.19 (VS1_2)
unnamed: C81.1, L5.1, R27.1, U14.22 (VS2_1), U14.24 (VS2_2)
VBUS: C57.2, C76.1, C77.1, C78.1, C79.1, C88.1, C89.1, C90.1, C91.1, C92.1, D11.1 (K), D13.1 (K), D14.1 (K), D16.1 (K), J2.A4_B9 (VBUS), J2.B4_A9 (VBUS__1), R25.2, R34.1, R49.2, R61.2, R62.2, U10.5 (EN), U10.8 (IN), U11.1 (VIN4), U11.2 (VIN5), U11.3 (VIN6), U11.27 (VIN1), U11.28 (VIN2), U11.29 (VIN3), U14.18 (VP1), U14.23 (VP2)

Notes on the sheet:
JST Debug Connector
12MHz Crystal
Flash 4MB
-> TO TAD5112
CLASS D AMP Stage 47.5k / (3.3k+8.2k) = 4.05 V/V or 12.5dB
3.3V ---> 5V
-> TO HUB75
^ISNS^
Designed by Isaac Olson
-> TO PD CONTROLLER
OP AMP Stage 34.8k / 10k = 3.48V/V or 10.8dB Original TLC082 on ref design updated with TLV9162
EPR POWER MANAGEMENT
CONTROL
TAD5112 DAC
HUB75 DATA OUT + LEVEL SHIFTERS
HIGH CURRENT 5V POWER MANAGEMENT
V / I Sensing

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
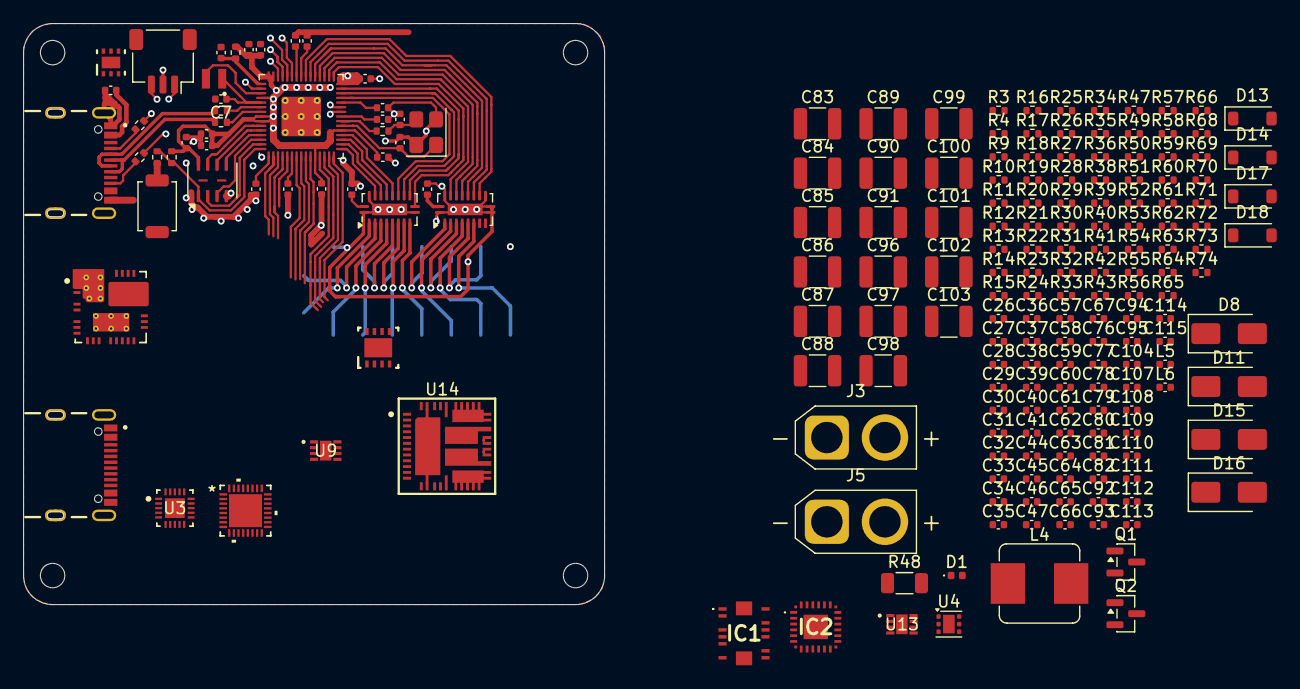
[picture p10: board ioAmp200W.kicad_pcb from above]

Board: 6 copper layers, 50.0 x 50.0 mm, 203 parts (1 on the bottom side), 143 nets.

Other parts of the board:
R3#2, R4#2: 5.1k; R_0402_1005Metric

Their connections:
GND: R3#2.1, R4#2.1; also elsewhere on the board
unnamed 118: R4#2.2; also elsewhere on the board
unnamed 119: R3#2.2; also elsewhere on the board

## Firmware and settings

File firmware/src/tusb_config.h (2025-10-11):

/*
 * The MIT License (MIT)
 *
 * Copyright (c) 2020 Ha Thach (tinyusb.org)
 * Copyright (c) 2020 Jerzy Kasenberg
 *
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
 */

#ifndef _TUSB_CONFIG_H_
#define _TUSB_CONFIG_H_

#ifdef __cplusplus
extern "C" {
#endif

#include "usb_descriptors.h"

//--------------------------------------------------------------------+
// Board Specific Configuration
//--------------------------------------------------------------------+

// RHPort number used for device can be defined by board.mk, default to port 0
#ifndef BOARD_TUD_RHPORT
#define BOARD_TUD_RHPORT      0
#endif

// RHPort max operational speed can defined by board.mk
#ifndef BOARD_TUD_MAX_SPEED
#define BOARD_TUD_MAX_SPEED   OPT_MODE_DEFAULT_SPEED
#endif

//--------------------------------------------------------------------
// Common Configuration
//--------------------------------------------------------------------

// defined by compiler flags for flexibility
#ifndef CFG_TUSB_MCU
#error CFG_TUSB_MCU must be defined
#endif

#ifndef CFG_TUSB_OS
#define CFG_TUSB_OS           OPT_OS_NONE
#endif

#ifndef CFG_TUSB_DEBUG
#define CFG_TUSB_DEBUG        0
#endif

// Enable Device stack
#define CFG_TUD_ENABLED       1

// Default is max speed that hardware controller could support with on-chip PHY
#define CFG_TUD_MAX_SPEED     BOARD_TUD_MAX_SPEED

/* USB DMA on some MCUs can only access a specific SRAM region with restriction on alignment.
 * Tinyusb use follows macros to declare transferring memory so that they can be put
 * into those specific section.
 * e.g
 * - CFG_TUSB_MEM SECTION : __attribute__ (( section(".usb_ram") ))
 * - CFG_TUSB_MEM_ALIGN   : __attribute__ ((aligned(4)))
 */
#ifndef CFG_TUSB_MEM_SECTION
#define CFG_TUSB_MEM_SECTION
#endif

#ifndef CFG_TUSB_MEM_ALIGN
#define CFG_TUSB_MEM_ALIGN        __attribute__ ((aligned(4)))
#endif

//--------------------------------------------------------------------
// DEVICE CONFIGURATION
//--------------------------------------------------------------------

#ifndef CFG_TUD_ENDPOINT0_SIZE
#define CFG_TUD_ENDPOINT0_SIZE    64
#endif

//------------- CLASS -------------//
#define CFG_TUD_CDC               1
#define CFG_TUD_MSC               0
#define CFG_TUD_HID               0
#define CFG_TUD_MIDI              0
#define CFG_TUD_AUDIO             1
#define CFG_TUD_VENDOR            0

//--------------------------------------------------------------------
// AUDIO CLASS DRIVER CONFIGURATION
//--------------------------------------------------------------------

#define CFG_TUD_AUDIO_FUNC_1_DESC_LEN                                TUD_AUDIO_HEADSET_STEREO_DESC_LEN
#define CFG_TUD_AUDIO_FUNC_1_N_AS_INT                                1

// How many formats are used, need to adjust USB descriptor if changed
#define CFG_TUD_AUDIO_FUNC_1_N_FORMATS                               2

// Audio format type I specifications
#if defined(__RX__)
#define CFG_TUD_AUDIO_FUNC_1_MAX_SAMPLE_RATE                         48000     // 16bit/48kHz is the best quality for Renesas RX
#else
#define CFG_TUD_AUDIO_FUNC_1_MAX_SAMPLE_RATE                         96000     // Allow 24bit/96kHz streaming while still fitting within FS bandwidth
#endif
#define CFG_TUD_AUDIO_FUNC_1_N_CHANNELS_TX                           0
#define CFG_TUD_AUDIO_FUNC_1_N_CHANNELS_RX                           2         // Stereo playback

// 16bit in 16bit slots
#define CFG_TUD_AUDIO_FUNC_1_FORMAT_1_N_BYTES_PER_SAMPLE_TX          2
#define CFG_TUD_AUDIO_FUNC_1_FORMAT_1_RESOLUTION_TX                  16
#define CFG_TUD_AUDIO_FUNC_1_FORMAT_1_N_BYTES_PER_SAMPLE_RX          2
#define CFG_TUD_AUDIO_FUNC_1_FORMAT_1_RESOLUTION_RX                  16

#if defined(__RX__)
// 8bit in 8bit slots
#define CFG_TUD_AUDIO_FUNC_1_FORMAT_2_N_BYTES_PER_SAMPLE_TX          1
#define CFG_TUD_AUDIO_FUNC_1_FORMAT_2_RESOLUTION_TX                  8
#define CFG_TUD_AUDIO_FUNC_1_FORMAT_2_N_BYTES_PER_SAMPLE_RX          1
#define CFG_TUD_AUDIO_FUNC_1_FORMAT_2_RESOLUTION_RX                  8
#else
// 24bit in 32bit slots
#define CFG_TUD_AUDIO_FUNC_1_FORMAT_2_N_BYTES_PER_SAMPLE_TX          4
#define CFG_TUD_AUDIO_FUNC_1_FORMAT_2_RESOLUTION_TX                  24
#define CFG_TUD_AUDIO_FUNC_1_FORMAT_2_N_BYTES_PER_SAMPLE_RX          4
#define CFG_TUD_AUDIO_FUNC_1_FORMAT_2_RESOLUTION_RX                  24
#endif

// EP and buffer size - for isochronous EP´s, the buffer and EP size are equal (different sizes would not make sense)
#define CFG_TUD_AUDIO_ENABLE_EP_IN                0

#if CFG_TUD_AUDIO_ENABLE_EP_IN
#define CFG_TUD_AUDIO_FUNC_1_FORMAT_1_EP_SZ_IN    TUD_AUDIO_EP_SIZE(CFG_TUD_AUDIO_FUNC_1_MAX_SAMPLE_RATE, CFG_TUD_AUDIO_FUNC_1_FORMAT_1_N_BYTES_PER_SAMPLE_TX, CFG_TUD_AUDIO_FUNC_1_N_CHANNELS_TX)
#define CFG_TUD_AUDIO_FUNC_1_FORMAT_2_EP_SZ_IN    TUD_AUDIO_EP_SIZE(CFG_TUD_AUDIO_FUNC_1_MAX_SAMPLE_RATE, CFG_TUD_AUDIO_FUNC_1_FORMAT_2_N_BYTES_PER_SAMPLE_TX, CFG_TUD_AUDIO_FUNC_1_N_CHANNELS_TX)
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
